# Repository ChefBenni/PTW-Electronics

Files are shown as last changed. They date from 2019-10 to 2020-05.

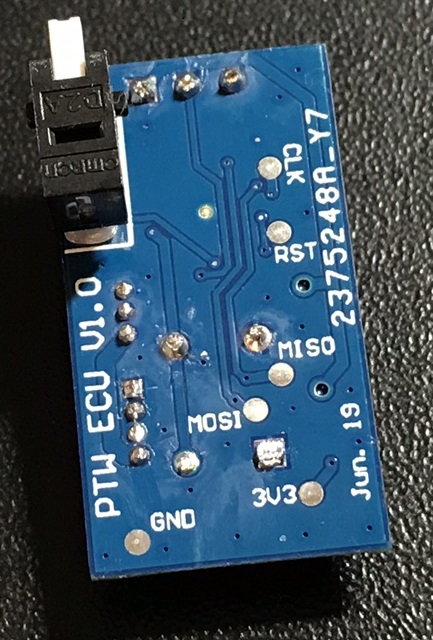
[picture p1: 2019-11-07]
ECU/V1.0 - Systema based/pictures/ECU_assembled_back.JPEG

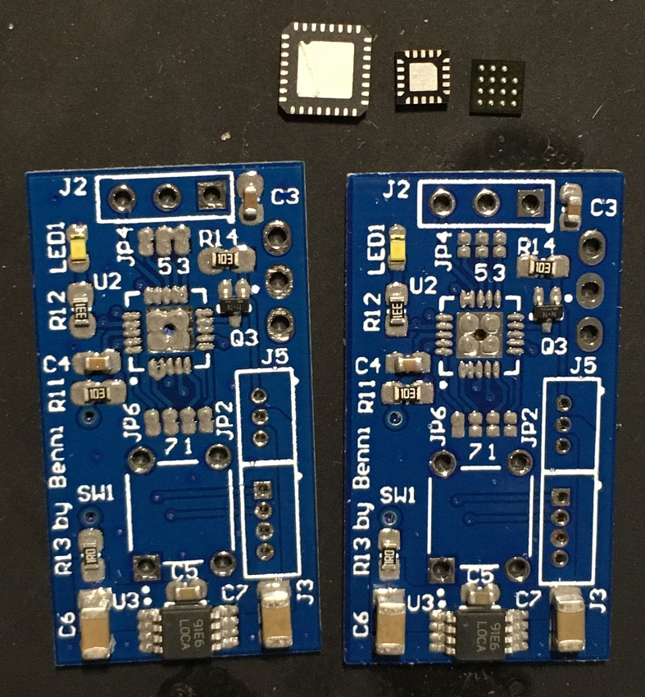
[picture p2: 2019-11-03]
ECU/V1.0 - Systema based/pictures/ECU_assmbled_problem.JPG

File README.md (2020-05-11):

# PTW-Electronics
Open Source Platform for the PTW airsoft system

This project is split up into two main groups. Original Systema PTW PCB design and improved versions for implementations of features of solving known issues.

Update 11.05.2020:
Original Systema ECU design works and is tested. Current software version V1.14

Improved ECU design works and is tested. Current software version V1.14

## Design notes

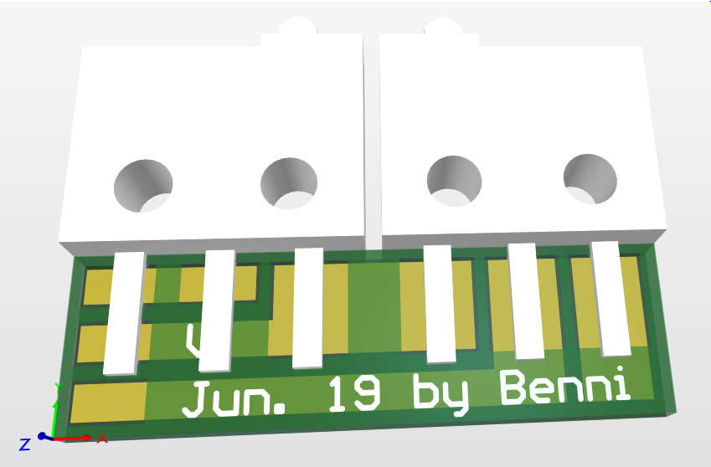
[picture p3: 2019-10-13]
Selector/V1.0 - basic design/pictures/Altium Selector ECAD V1.0_front.PNG

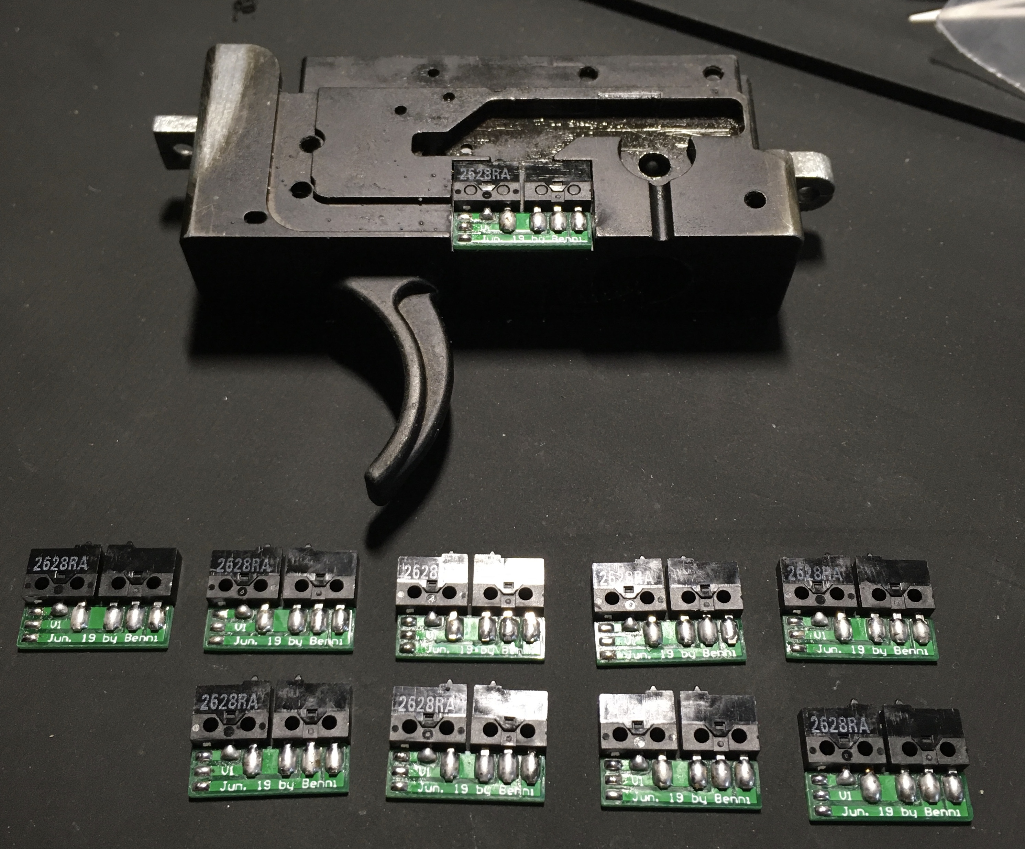
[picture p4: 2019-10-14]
Selector/V1.0 - basic design/pictures/51310E7E-7A2E-4038-BCB8-E1461A7ACF0A.jpeg

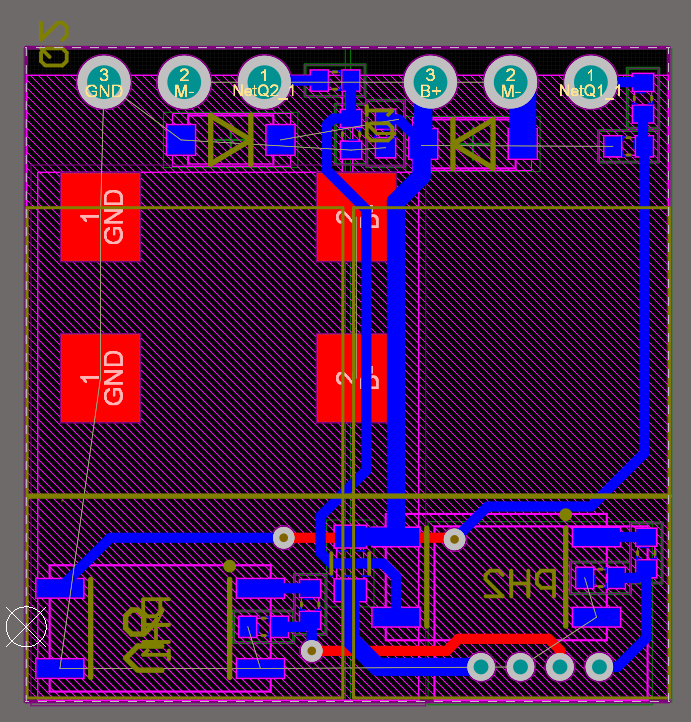
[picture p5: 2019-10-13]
Mosfet/V1.1 - basic design with fuse/pictures/Altium Mosfet ECAD V1.1_Top layer.PNG

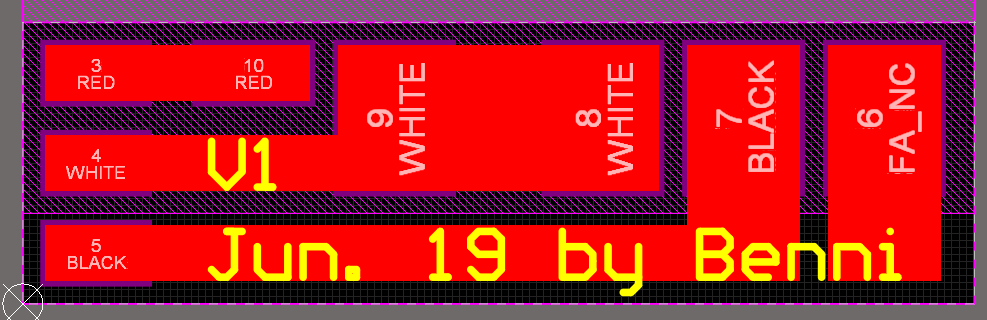
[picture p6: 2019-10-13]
Selector/V1.0 - basic design/pictures/Altium Selector ECAD V1.0_Top layer.PNG

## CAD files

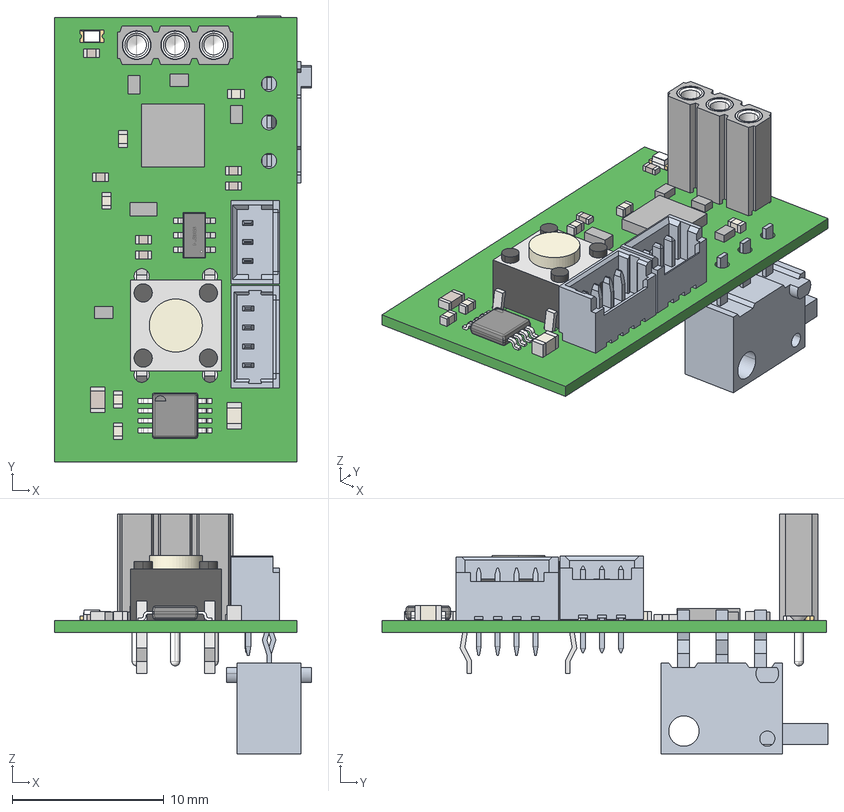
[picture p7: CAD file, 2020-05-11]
ECU/V2.0 - New design/Altium files/PTW_ECU_CP_V1.0.step
16.9 x 29.4 x 15.8 mm
Extruded x 45
housing
cover
base x 2
Polarity_Mark
SOT475-SC74
mill-max-801-93-003-10-001000_P8XX-11-014-00-000000_ P803-11-014-00-000000
mill-max-801-93-003-10-001000_1304_1304-0-00-01-00-00-03-0 x 3
b3f-1006 x 2
D2A_1120_ACTUATOR
D2A_1120_BASE
BODY_MUY08A
LEAD_MUY08A x 8
EXP_PAD_MUY08A

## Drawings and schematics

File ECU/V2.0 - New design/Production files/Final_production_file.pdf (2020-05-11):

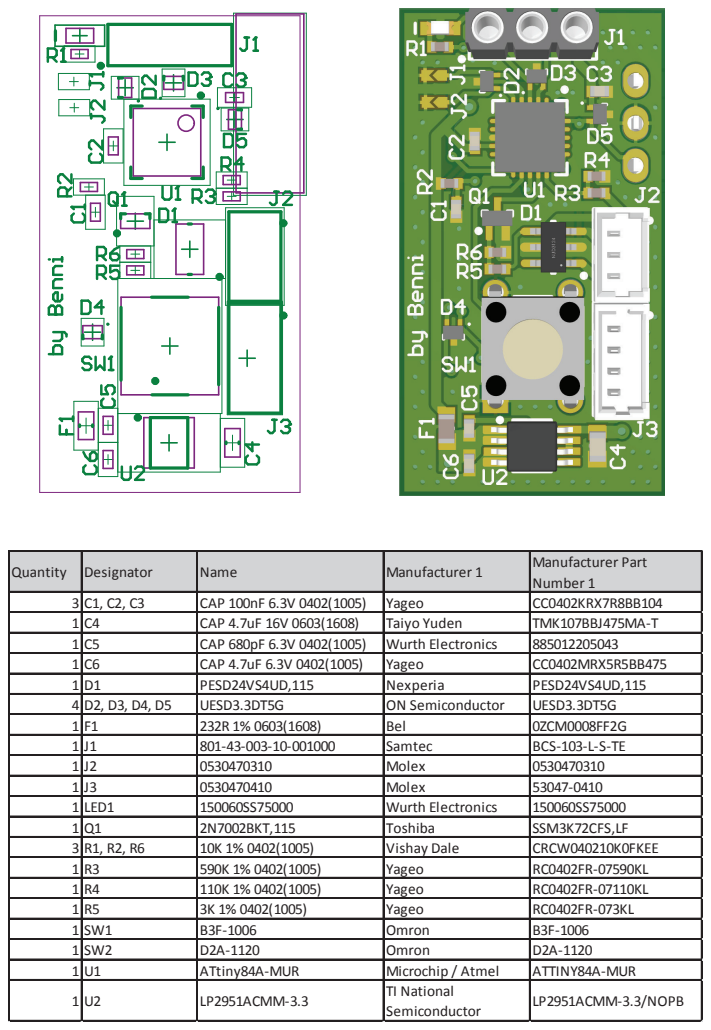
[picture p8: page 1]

Quantity | Designator | Name | Manufacturer 1 | Manufacturer Part Number 1

3 | C1, C2, C3 | CAP 100nF 6.3V 0402(1005) | Yageo | CC0402KRX7R8BB104
1 | C4 | CAP 4.7uF 16V 0603(1608) | Taiyo Yuden | TMK107BBJ475MA-T
1 | C5 | CAP 680pF 6.3V 0402(1005) | Wurth Electronics | 885012205043
1 | C6 | CAP 4.7uF 6.3V 0402(1005) | Yageo | CC0402MRX5R5BB475
1 | D1 | PESD24VS4UD,115 | Nexperia | PESD24VS4UD,115
4 | D2, D3, D4, D5 | UESD3.3DT5G | ON Semiconductor | UESD3.3DT5G
1 | F1 | 232R 1% 0603(1608) | Bel | 0ZCM0008FF2G
1 | J1 | 801-43-003-10-001000 | Samtec | BCS-103-L-S-TE
1 | J2 | 0530470310 | Molex | 0530470310
1 | J3 | 0530470410 | Molex | 53047-0410
1 | LED1 | 150060SS75000 | Wurth Electronics | 150060SS75000
1 | Q1 | 2N7002BKT,115 | Toshiba | SSM3K72CFS,LF
3 | R1, R2, R6 | 10K 1% 0402(1005) | Vishay Dale | CRCW040210K0FKEE
1 | R3 | 590K 1% 0402(1005) | Yageo | RC0402FR-07590KL
1 | R4 | 110K 1% 0402(1005) | Yageo | RC0402FR-07110KL
1 | R5 | 3K 1% 0402(1005) | Yageo | RC0402FR-073KL
1 | SW1 | B3F-1006 | Omron | B3F-1006
1 | SW2 | D2A-1120 | Omron | D2A-1120
1 | U1 | ATtiny84A-MUR | Microchip / Atmel | ATTINY84A-MUR
1 | U2 | LP2951ACMM-3.3 | TI National Semiconductor | LP2951ACMM-3.3/NOPB

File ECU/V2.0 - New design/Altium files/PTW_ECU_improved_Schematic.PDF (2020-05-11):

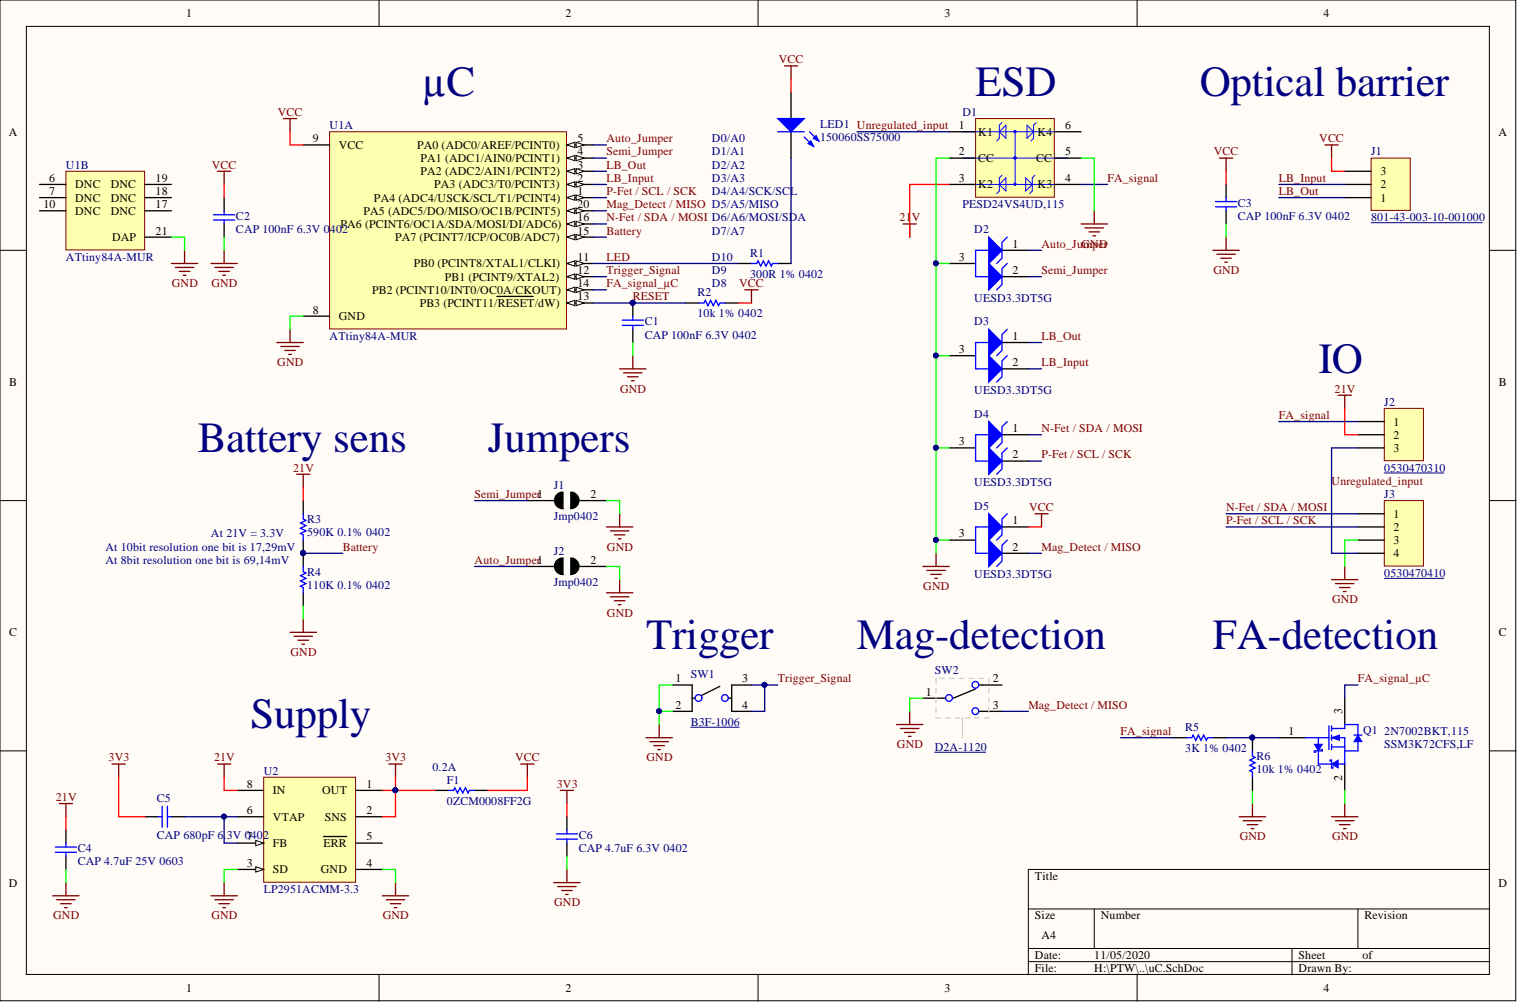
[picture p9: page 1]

At 10bit resolution one bit is 17,29mV
At 8bit resolution one bit is 69,14mV

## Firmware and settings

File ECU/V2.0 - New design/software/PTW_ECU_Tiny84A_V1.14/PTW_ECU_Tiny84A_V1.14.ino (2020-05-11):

/*
  PTW ECU V1.14

  Main controller programm for Systema PTW improved ECU. NOT pinout compatible with original ECU.

  The circuit:
  - ATtiny84A
  - compatible boardlayout with same pinout

  created 06. Nov.2019
  by Benjamin Burg <https://github.com/ChefBenni/PTW-Electronics>
  modified 11 May 2020
  by Benjamin Burg
                                                                        
  This example code is in the public domain.
  https://github.com/ChefBenni/PTW-Electronics
*/


//   ---   --  |\  | -- -----   /\   |\  | -----
//  |     |  | | \ | \    |    /__\  | \ |   |
//   ---   --  |  \| --   |   /    \ |  \|   |
// constants won't change. They're used here to set pin numbers:
const int Mag_Sig_Pin = 5;    // the number of the magazine detection switch pin  - Low active  - pull-up
const int Trig_Sig_Pin = 9;   // the number of the trigger buttin pin             - Low active  - pull-up
const int LedPin = 10;        // the number of the LED pin                        - High active
const int FA_Sig_Pin = 8;     // the number of the full auto signal pin           - Low active  - pull-up
const int LS_Input_Pin = 3;   // the number of the light barrier detector pin     - Low active
const int LS_Led_Pin = 2;    // the number of the light barrier LED pin          - Low active
const int FET_On_Pin = 6;    // the number of the motor turn MOSFET pin          - High active
const int FET_Brake_Pin = 4; // the number of the brake MOSFET pin               - High active
const int Jumper1_Pin = 0;    // the number of the jumper1 pin                    - Low active  - pull-up
const int Jumper2_Pin = 1;    // the number of the jumper2 pin                    - Low active  - pull-up

// constant time values
const int MaxCycleTime = 150; // maximum cycle time before error occures  [ms]
const int BrakeDelay = 100;   // breaking delay to avoid shot through     [µs]
const int BrakeTime = 100;    // breaking time of the motor               [ms]
const int DebounceTime = 200; // time for trigger debounce                [µs]
const int LSDelay = 500;      // light barrier delay *measured 250µs*     [µs]


//  \    /   /\   |  |  |   /\    
//   \  /   /--\  |-\   |  /--\   
//    \/   /    \ |  \  | /    \  
// variables will change
int MagState = LOW;             // variable for reading the magazine button status
int TriggerState = LOW;         // variable for reading the trigger button status
int FaState = LOW;              // variable for reading the full auto status
int LsState = HIGH;             // variable for reading the light barrier status
int BrakeState = LOW;           // saves if motor is still breaking
int ErrorBrake = LOW;           // saves if motor breaked because of an error
int BreakeIndicator = HIGH;     // indicator if motor is stopped
long previousMillis = 0;        // internal calculation time for rotation
unsigned long currentMillis = 0;// internal calculation time for rotation


//  -- |-- ----- |  | |--|
//  \  |--   |   |  | |--|
//  -- |--   |   |__| |
void setup() {
  // inputs
  pinMode(Mag_Sig_Pin, INPUT);    // initialize the magazine button pin as an input
  pinMode(Trig_Sig_Pin, INPUT);   // initialize the trigger button pin as an input
  pinMode(FA_Sig_Pin, INPUT);     // initialize the full auto pin as an input
  pinMode(LS_Input_Pin, INPUT);   // initialize the light barrier pin as an input
  pinMode(Jumper1_Pin, INPUT);    // initialize the jumper 1 pin as an input
  pinMode(Jumper2_Pin, INPUT);    // initialize the jumper 2 pin as an input

  // pull resistors
  digitalWrite(Mag_Sig_Pin, HIGH);     // turn on pull-up resitor
  digitalWrite(Trig_Sig_Pin, HIGH);    // turn on pull-up resitor
  digitalWrite(FA_Sig_Pin, HIGH);      // turn on pull-up resitor
  digitalWrite(Jumper1_Pin, HIGH);     // turn on pull-up resitor
  digitalWrite(Jumper2_Pin, HIGH);     // turn on pull-up resitor
  
  // outputs
  pinMode(LedPin, OUTPUT);        // initialize the LED pin as an output
  pinMode(LS_Led_Pin, OUTPUT);    // initialize the light barrier LED pin as an output
  pinMode(FET_On_Pin, OUTPUT);    // initialize the turn MOSFET pin as an output
  pinMode(FET_Brake_Pin, OUTPUT); // initialize the brake MOSFET pin as an output

  // outpus initial start state
  digitalWrite(LedPin, HIGH);        // turn the signal LED off
  digitalWrite(LS_Led_Pin, HIGH);   // turn the light barrier LED off
  digitalWrite(FET_On_Pin, LOW);    // turn the turn MOSFET off
  digitalWrite(FET_Brake_Pin, LOW); // turn the brake MOSFET off

  // blink at startup
  digitalWrite(LedPin, LOW);    // turn the LED on (LOW is the voltage level)
  delay(50);                    // wait for 50ms
  digitalWrite(LedPin, HIGH);   // turn the LED off by making the voltage LOW
  delay(50);                    // wait for 50ms
  digitalWrite(LedPin, LOW);    // turn the LED on
  delay(50);                    // wait for 50ms
  digitalWrite(LedPin, HIGH);   // turn the LED off
}


//  |\/|  /\  || |\ |
//  |  | /--\ || | \|
void loop() {
  // read the state of the pushbutton values:
  MagState = digitalRead(Mag_Sig_Pin);          // reads magazine state
  TriggerState = digitalRead(Trig_Sig_Pin);     // reads trigger state
  FaState = digitalRead(FA_Sig_Pin);            // reads semi / fullauto state
  BrakeTimeCheck();                             // check if breaking time reached

  if (MagState == LOW && TriggerState == LOW){  // checks if the trigger is pressed and magazine not empty
    if (FaState == HIGH){                       // if it's on semi
      semi();                                   // jump to semi()
    }
    else{                                       // if it's on auto
      automode();                               // jump to automode()
    }
  }

  else if (MagState == HIGH && TriggerState == LOW){  // blink if trigger is pressed but magazine is empty
    digitalWrite(LedPin, LOW);                       // turn the LED on (HIGH is the voltage level)
    delay(50);                                        // wait for 50ms
    BrakeTimeCheck();                                 // check if breaking time reached
    digitalWrite(LedPin, HIGH);                        // turn the LED off by making the voltage LOW
    delay(50);                                        // wait for 50ms
    BrakeTimeCheck();                                 // check if breaking time reached
      
    while (TriggerState == LOW){                      // wait while trigger is pushed
      TriggerState = digitalRead(Trig_Sig_Pin);       // reads trigger state
      BrakeTimeCheck();                               // check if breaking time reached
    }
  }
}


//  --  |-- |\_/| |
//  \   |-- |   | |
//  --  |-- |   | |
void semi()
{
  MotorOn();      // turn motor on
  Cycle();        // do a cycle
  MotorOff();     // turn motor off and brake
  Debounce();     // wait for trigger not pressed including debounce
  loop();         // jumps to main
}


//    /\   |    | -----  /--\
//   /--\  |    |   |   |    |
//  /    \  \__/    |    \__/
void automode()
{
  MotorOn();                                      // turn motor on
  while (MagState == LOW && TriggerState == LOW){ // cycle while trigger is pushed
    MagState = digitalRead(Mag_Sig_Pin);          // reads magazine state
    TriggerState = digitalRead(Trig_Sig_Pin);     // reads trigger state
    Cycle();                                      // do a cycle
  }
  MotorOff();                         // turn motor off and brake
  Debounce();                         // wait for trigger not pressed including debounce
  loop();                             // jumps to main
}


//  |-- |  |  |  |
//  |-- |-\   |-\
//  |-- |  \  |  \

void problem()
{
  if (ErrorBrake == LOW){             // if errorprogram starts for the first time brake motor
    MotorOff();                       // turn motor off and brake
    ErrorBrake = HIGH;                // write that the motor alreade stopped
  }
  
  // let the LED flash for signalling the error
  digitalWrite(LedPin, LOW);         // turn the LED on
  delay(100);                         // wait for 100ms
  digitalWrite(LedPin, HIGH);          // turn the LED off
  delay(100);                         // wait for 100ms

  problem();                          // jump back to the start of the error programm for contious flashing
}


void MotorOn()
{
  if (BreakeIndicator == LOW){        // check if motor is already stopped or still braking
    digitalWrite(FET_Brake_Pin, LOW); // turns the brake MOSFET off
    delayMicroseconds(BrakeDelay);    // turn-on-off delay time to avoid shot-through
  }
  digitalWrite(FET_On_Pin, HIGH);     // turn the turn MOSFET on
  digitalWrite(LS_Led_Pin, LOW);      // turn the light barrier LED on
  delayMicroseconds(LSDelay);         // wait for light barrier to start detecting
}

void MotorOff()
{
  digitalWrite(FET_On_Pin, LOW);      // turn the turn MOSFET off
  digitalWrite(LS_Led_Pin, HIGH);     // turn the light barrier LED off
  delayMicroseconds(BrakeDelay);      // turn-off delay time to avoid shot-through
  digitalWrite(FET_Brake_Pin, HIGH);  // turn the brake MOSFET on
  previousMillis = millis();          // read start time before brake time starts
  BreakeIndicator = LOW;              // reset braking indicator that motor is still spinning
}

void BrakeTimeCheck()
{
  currentMillis = millis();                       // reads current time and stores it to save timers
  // if current time - start time is bigger then braking time and motor is still spinning
  if(currentMillis - previousMillis > BrakeTime && BreakeIndicator == LOW){
    BrakingEnd();                                 // jump to end of breaking time           
  }
}

void BrakingEnd()
{
  digitalWrite(FET_Brake_Pin, LOW);   // turns the brake MOSFET off
  delayMicroseconds(BrakeDelay);      // turn-on-off delay time to avoid shot-through
  BreakeIndicator = HIGH;             // save that motor is stopped
}

void Debounce()
{
  TriggerState = digitalRead(Trig_Sig_Pin);       // reads trigger state
  while (TriggerState == LOW){                    // waits till trigger is not pressed
    delayMicroseconds(DebounceTime);              // button debounce delay time
    TriggerState = digitalRead(Trig_Sig_Pin);     // reads trigger state
    BrakeTimeCheck();                             // check if breaking time reached
  }
  
  // second test if trigger not pressed and debounced to avoid double shots
  delayMicroseconds(DebounceTime);                // button debounce delay time
  TriggerState = digitalRead(Trig_Sig_Pin);       // reads trigger state
  while (TriggerState == LOW){                    // waits till trigger is not pressed
    delayMicroseconds(DebounceTime);              // button debounce delay time
    TriggerState = digitalRead(Trig_Sig_Pin);     // reads trigger state
    BrakeTimeCheck();                             // check if breaking time reached
  } 
}

void Cycle()
{
  LsState = digitalRead(LS_Input_Pin);                  // reads in the gearposition from the light barrier
  previousMillis = millis();                            // read start time before cycle start
  while (LsState == LOW){                               // if starts at detection position wait for cycle
    LsState = digitalRead(LS_Input_Pin);                // reads in the gearposition from the light barrier
    currentMillis = millis();                           // reads current time and stores it to save timers
    if(currentMillis - previousMillis > MaxCycleTime){  // if current time - start time bigger then max cycle time
      problem();                      
    }
  }
  while (LsState == HIGH){                              // waits for full cycle completed
    LsState = digitalRead(LS_Input_Pin);                // reads in the gearposition from the light barrier
    currentMillis = millis();                           // reads current time and stores it to save timers
    if(currentMillis - previousMillis > MaxCycleTime){  // if current time - start time bigger then max cycle time
      problem();                      
    }
  }
}

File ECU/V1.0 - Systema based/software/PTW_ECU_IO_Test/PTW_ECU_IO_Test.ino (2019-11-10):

/*
  PTW ECU V1.0

  Turns on and off a light emitting diode(LED) connected to digital pin 13,
  when pressing a pushbutton attached to pin 2.

  The circuit:
  - LED attached from pin 13 to ground
  - pushbutton attached to pin 2 from +5V
  - 10K resistor attached to pin 2 from ground

  - Note: on most Arduinos there is already an LED on the board
    attached to pin 13.

  created 06. Nov.2019
  by Benjamin Burg <http://www.>
  modified 07 Nov. 2019
  by Benjamin Burg

  This example code is in the public domain.

  https://github.com/ChefBenni/PTW-Electronics
*/

// constants won't change. They're used here to set pin numbers:
const int Mag_Sig_Pin = 3;    // the number of the magazine detection switch pin  - Low active  - pull-up
const int Trig_Sig_Pin = 7;   // the number of the trigger buttin pin             - Low active  - pull-up
const int LedPin = 16;        // the number of the LED pin                        - High active
const int FA_Sig_Pin = 8;     // the number of the full auto signal pin           - Low active  - pull-up
const int LS_Input_Pin = 4;   // the number of the light barrier detector pin     - Low active
const int LS_Led_Pin = 13;    // the number of the light barrier LED pin          - Low active
const int FET_On_Pin = 15;    // the number of the motor turn MOSFET pin          - High active
const int FET_Brake_Pin = 14; // the number of the brake MOSFET pin               - High active
const int Jumper1_Pin = 5;    // the number of the jumper1 pin                    - Low active  - pull-up
const int Jumper2_Pin = 6;    // the number of the jumper2 pin                    - Low active  - pull-up
const int Jumper3_Pin = 10;   // the number of the jumper3 pin                    - Low active  - pull-up
const int Jumper4_Pin = 12;   // the number of the jumper4 pin                    - Low active  - pull-up
const int Jumper5_Pin = 11;   // the number of the jumper5 pin                    - Low active  - pull-up
const int Jumper6_Pin = 0;    // the number of the jumper6 pin                    - Low active  - pull-up
const int Jumper7_Pin = 1;    // the number of the jumper7 pin                    - Low active  - pull-up

// variables will change:
int MagState = 0;             // variable for reading the magazine button status
int TriggerState = 0;         // variable for reading the trigger button status
int FaState = 0;              // variable for reading the full auto status
int LsState = 0;              // variable for reading the light barrier status


void setup() {
  // inputs
  pinMode(Mag_Sig_Pin, INPUT);    // initialize the pushbutton pin as an input
  pinMode(Trig_Sig_Pin, INPUT);   // initialize the pushbutton pin as an input
  pinMode(FA_Sig_Pin, INPUT);     // initialize the pushbutton pin as an input
  pinMode(LS_Input_Pin, INPUT);   // initialize the pushbutton pin as an input
  pinMode(Jumper1_Pin, INPUT);    // initialize the pushbutton pin as an input
  pinMode(Jumper2_Pin, INPUT);    // initialize the pushbutton pin as an input
  pinMode(Jumper3_Pin, INPUT);    // initialize the pushbutton pin as an input
  pinMode(Jumper4_Pin, INPUT);    // initialize the pushbutton pin as an input
  pinMode(Jumper5_Pin, INPUT);    // initialize the pushbutton pin as an input
  pinMode(Jumper6_Pin, INPUT);    // initialize the pushbutton pin as an input
  pinMode(Jumper7_Pin, INPUT);    // initialize the pushbutton pin as an input

  // pull resistors
  digitalWrite(Mag_Sig_Pin, HIGH);     // turn on pull-up resitor
  digitalWrite(Trig_Sig_Pin, HIGH);    // turn on pull-up resitor
  digitalWrite(FA_Sig_Pin, HIGH);      // turn on pull-up resitor
  digitalWrite(Jumper1_Pin, HIGH);     // turn on pull-up resitor
  digitalWrite(Jumper2_Pin, HIGH);     // turn on pull-up resitor
  digitalWrite(Jumper3_Pin, HIGH);     // turn on pull-up resitor
  digitalWrite(Jumper4_Pin, HIGH);     // turn on pull-up resitor
  digitalWrite(Jumper5_Pin, HIGH);     // turn on pull-up resitor
  digitalWrite(Jumper6_Pin, HIGH);     // turn on pull-up resitor
  digitalWrite(Jumper7_Pin, HIGH);     // turn on pull-up resitor
  
  // outputs
  pinMode(LedPin, OUTPUT);        // initialize the LED pin as an output
  pinMode(LS_Led_Pin, OUTPUT);    // initialize the light barrier LED pin as an output
  pinMode(FET_On_Pin, OUTPUT);    // initialize the turn MOSFET pin as an output
  pinMode(FET_Brake_Pin, OUTPUT); // initialize the brake MOSFET pin as an output

  // outpus initial start state
  digitalWrite(LedPin, LOW);        // turn the signal LED off
  digitalWrite(LS_Led_Pin, LOW);    // turn the light barrier LED on
  digitalWrite(FET_On_Pin, LOW);    // turn the turn MOSFET off
  digitalWrite(FET_Brake_Pin, LOW); // turn the brake MOSFET off

  digitalWrite(LedPin, HIGH);   // turn the LED on (HIGH is the voltage level)
  delay(50);                    // wait for 50ms
  digitalWrite(LedPin, LOW);    // turn the LED off by making the voltage LOW
  delay(50);                    // wait for 50ms
  digitalWrite(LedPin, HIGH);   // turn the LED on (HIGH is the voltage level)
  delay(50);                    // wait for 50ms
  digitalWrite(LedPin, LOW);    // turn the LED off by making the voltage LOW
}

void loop() {
  // read the state of the pushbutton value:
  MagState = digitalRead(Mag_Sig_Pin);
  TriggerState = digitalRead(Trig_Sig_Pin);
  FaState = digitalRead(FA_Sig_Pin);
  LsState = digitalRead(LS_Input_Pin);

  // check if the pushbutton is pressed. If it is, the buttonState is HIGH:
  if (MagState == LOW || TriggerState == LOW || FaState == LOW || LsState == HIGH) {
    // turn LED on:
    digitalWrite(LedPin, HIGH);
    digitalWrite(FET_On_Pin, HIGH);
    digitalWrite(FET_Brake_Pin, HIGH);
    
  } else {
    // turn LED off:
    digitalWrite(LedPin, LOW);
    digitalWrite(FET_On_Pin, LOW);
    digitalWrite(FET_Brake_Pin, LOW);
  }
}

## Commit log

2019-10-13 Initial upload of SENS files
    [PTW_SENS.SchDoc, PTW_SENS_V1.PcbDoc, PTW_SENS_V1.PrjPcb]
2019-10-13 Mosfet files added
    [PTW_Mosfet.SchDoc, PTW_Mosfet_V1.0.PcbDoc, PTW_Mosfet_V1.0.PrjPcb]
2019-10-13 Selector PCB initial upload
    [PTW_Switch_Board.PrjPcb, PTW_Switch_Board_V1.PcbDoc, Switch_Board.SchDoc]
2019-10-14 Working PCB test
2019-10-27 ECU Soldering Tool with USB connector concept
2019-10-27 PCB Dummy test
2019-10-27 Added pictures with the printed soldering picture
2019-11-03 Problems while assembling
2019-11-07 First IO test of functional assembled ECU
2019-11-10 Added a picture of the bed of needles PCB
2020-05-11 Altium and gerber files
    Altium an gerber files uploaded for original version
    [IO.SchDoc, PTW_ECU_Original.PcbDoc, PTW_ECU_Original.PrjPcb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]
2020-05-11 First improved version
    Switched to ATTINY84A for ADC / battery voltage reading cabability.
    ESD protection added to all touchable pins.
    Maximum of 24V added, so plenty of headroom to go crazy
    I2C pins of ATTINY84 are the pins to communicate with the mosfet PCB for future two way communication implemented (work in progress)
    All production files added
    [PTW_ECU_CP_V1.0.PcbDoc, PTW_ECU_CP_V1.0.PrjPcb, PTW_ECU_CP_V1.0.step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]
2020-05-11 Two versions added
    Slight programm improvements and bugfixes
    [PTW_ECU_V1.13.ino, PTW_ECU_V1.14.ino]
2020-05-11 Software added
    Software of V1.14 rewritten for Attiny84A pinout according to schematics / attiny arduino core pinout
2020-05-11 Schematics added
